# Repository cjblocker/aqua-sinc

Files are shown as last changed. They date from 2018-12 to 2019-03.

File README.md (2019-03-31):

# AquaSinc

A small home-made aquarium controller built around an ARM Cortex M4 STM32f and a Raspberry Pi

## Reference

- 1Bitsy Pinout [ https://github.com/esden/1BitSy ]

## Parts
- 3.3V LDO [ https://www.arrow.com/en/products/mcp1703a-3302edb/microchip-technology ]
- Green Chip LED [ https://www.arrow.com/en/products/kpg-1608vgc-a/kingbright ]

## Dev Instructions for Black Magic Probe

Putting these here because I forget...

1. `$ arm-none-eabi-gdb src/main.elf` or `make debug`
    Upon start up of gdb, these should automatically be exectured from .gdbinit
    ```bash
    (gdb) set target-async on
    (gdb) set confirm off
    (gdb) set mem inaccessible-by-default off
    (gdb) target extended-remote /dev/cu.usbmodem7BAB88A81
    (gdb) monitor version
    (gdb) monitor swdp_scan
    (gdb) attach 1
    ```
2. Load the program from the connected computer with `load`
3. Use any of the following to debug
    * `run` - start or restart the program
    * `start` - run till the beginning of the main function, restart if needed
    * `Ctrl-C` - interrupt the program while running
    * `continue` - resume running after being stopped
    * `next` - run next line of program (but don't step into functions)
    * `step` - like next, but steps into a function
    * `finish` - run till you leave the current function
    * `list [line number]` - show 10 lines surrounding [line number], current line by default
    * `info locals` - print out local variables
    * `set variable <var_name>=<value>` - set variable _var_name_ to _value_
    * `break <line_number>` - set a breakpoint at _line_number_
    * `info breakpoints` - list current breakpoints
    * `disable breakpoints`
    * `delete breakpoints`
    * `watch <var_name>` - set a watchpoint on variable _var_name_
    * `print <expression>` - evaluates expression and prints it
    * `printf <format_string>,<var_name>` - place _var_name_ in the format string at points with %d,%s,etc
    * `commands ... end` - execute the given commands after the previously created watchpoint is changed. 
        Example:
        ```bash
        (gdb) watch blink_count
        (gdb) commands
        > printf "blink extend condition %d\n", blink_count^4
        > end
        ```
4. If you make changes to main.c, you can run make from within gdb, followed by `load`.
5. `quit` to exit gdb or `Ctrl-D`

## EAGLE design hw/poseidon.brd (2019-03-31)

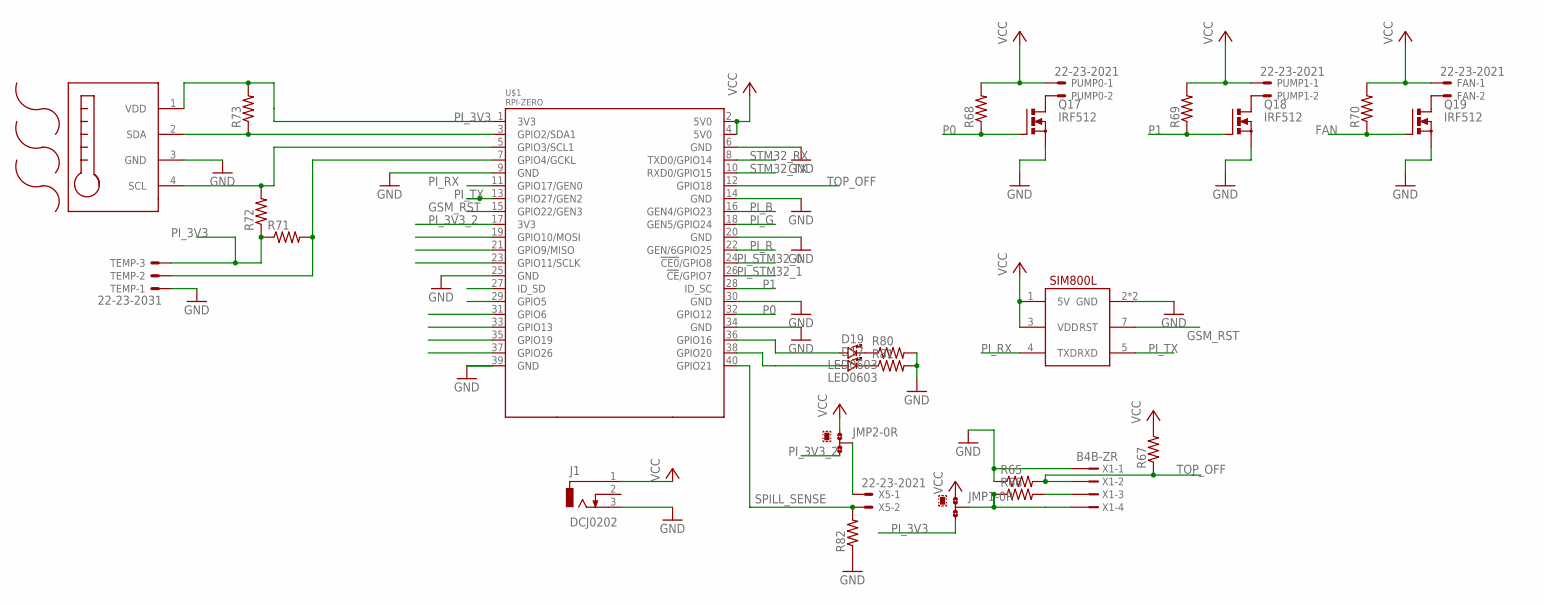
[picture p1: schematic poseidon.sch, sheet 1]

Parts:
D17, D19: LED0603; LED-0603
FAN: 22-23-2021
J1: DCJ0202
JMP1, JMP2: 0R-JUMPA; A0R-JMP
PUMP0, PUMP1: 22-23-2021
Q17, Q18, Q19: IRF512; TO220BV
R65, R66, R68, R69, R70, R71, R72, R73, R80, R81, R82: R-US_R0805; R0805
R67: R-US_M0805; M0805
TEMP: 22-23-2031
U$1: RPI-ZERO; RASPBERRYPI_BASTELSTUBE_V13_RASPI_BOARD_B+_FULL
U$3: AM2320; 4PIN_SMD
U$21: SIM800L; SIP
X1: B4B-ZR
X5: 22-23-2021

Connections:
FAN: Q19.G, R70.1; also elsewhere on the board
GND: J1.3, Q17.S, Q18.S, Q19.S, R65.1, R80.2, R81.2, R82.1, TEMP.1, U$1.6 (GND), U$1.9 (GND), U$1.14 (GND), U$1.20 (GND), U$1.25 (GND), U$1.30 (GND), U$1.34 (GND), U$1.39 (GND), U$3.3 (GND), U$21.2 (GND), U$21.6 (GND), X1.1; also elsewhere on the board
GSM_RST: U$1.15 (GPIO22/GEN3), U$21.7 (RST)
unnamed: PUMP0.2, Q17.D
unnamed: D19.C (CATHODE), R80.1
unnamed: R66.2, X1.3
unnamed: JMP1.2, R66.1, X1.4
unnamed: PUMP1.2, Q18.D
unnamed: D17.C (CATHODE), R81.1
unnamed: FAN.2, Q19.D
unnamed: R71.2, TEMP.2, U$1.7 (GPIO4/GCKL)
unnamed: R73.1, U$1.3 (GPIO2/SDA1), U$3.2 (SDA)
unnamed: R72.2, U$1.5 (GPIO3/SCL1), U$3.4 (SCL)
unnamed: D19.A (ANODE), U$1.36 (GPIO16)
unnamed: D17.A (ANODE), U$1.38 (GPIO20)
unnamed: JMP2.2, X5.1
P0: Q17.G, R68.1, U$1.32 (GPIO12)
P1: Q18.G, R69.1, U$1.28 (ID_SC)
PI_3V3: JMP1.3, R71.1, R72.1, R73.2, TEMP.3, U$1.1 (3V3), U$3.1 (VDD); also elsewhere on the board
PI_3V3_2: JMP2.3, U$1.17 (3V3)
PI_B: U$1.16 (GEN4/GPIO23); also elsewhere on the board
PI_G: U$1.18 (GEN5/GPIO24); also elsewhere on the board
PI_R: U$1.22 (GEN/6GPIO25); also elsewhere on the board
PI_RX: U$1.11 (GPIO17/GEN0), U$21.4 (TXD)
PI_STM32_0: U$1.24 (!CE0!/GPIO8); also elsewhere on the board
PI_STM32_1: U$1.26 (!CE!/GPIO7); also elsewhere on the board
PI_TX: U$1.13 (GPIO27/GEN2), U$21.5 (RXD)
SPILL_SENSE: R82.2, U$1.40 (GPIO21), X5.2
STM32_RX: U$1.8 (TXD0/GPIO14); also elsewhere on the board
STM32_TX: U$1.10 (RXD0/GPIO15); also elsewhere on the board
TOP_OFF: R65.2, R67.1, U$1.12 (GPIO18), X1.2
VCC: FAN.1, J1.1, JMP1.1, JMP2.1, PUMP0.1, PUMP1.1, R67.2, R68.2, R69.2, R70.2, U$1.2 (5V0), U$1.4 (5V0), U$21.1 (5V), U$21.3 (VDD); also elsewhere on the board

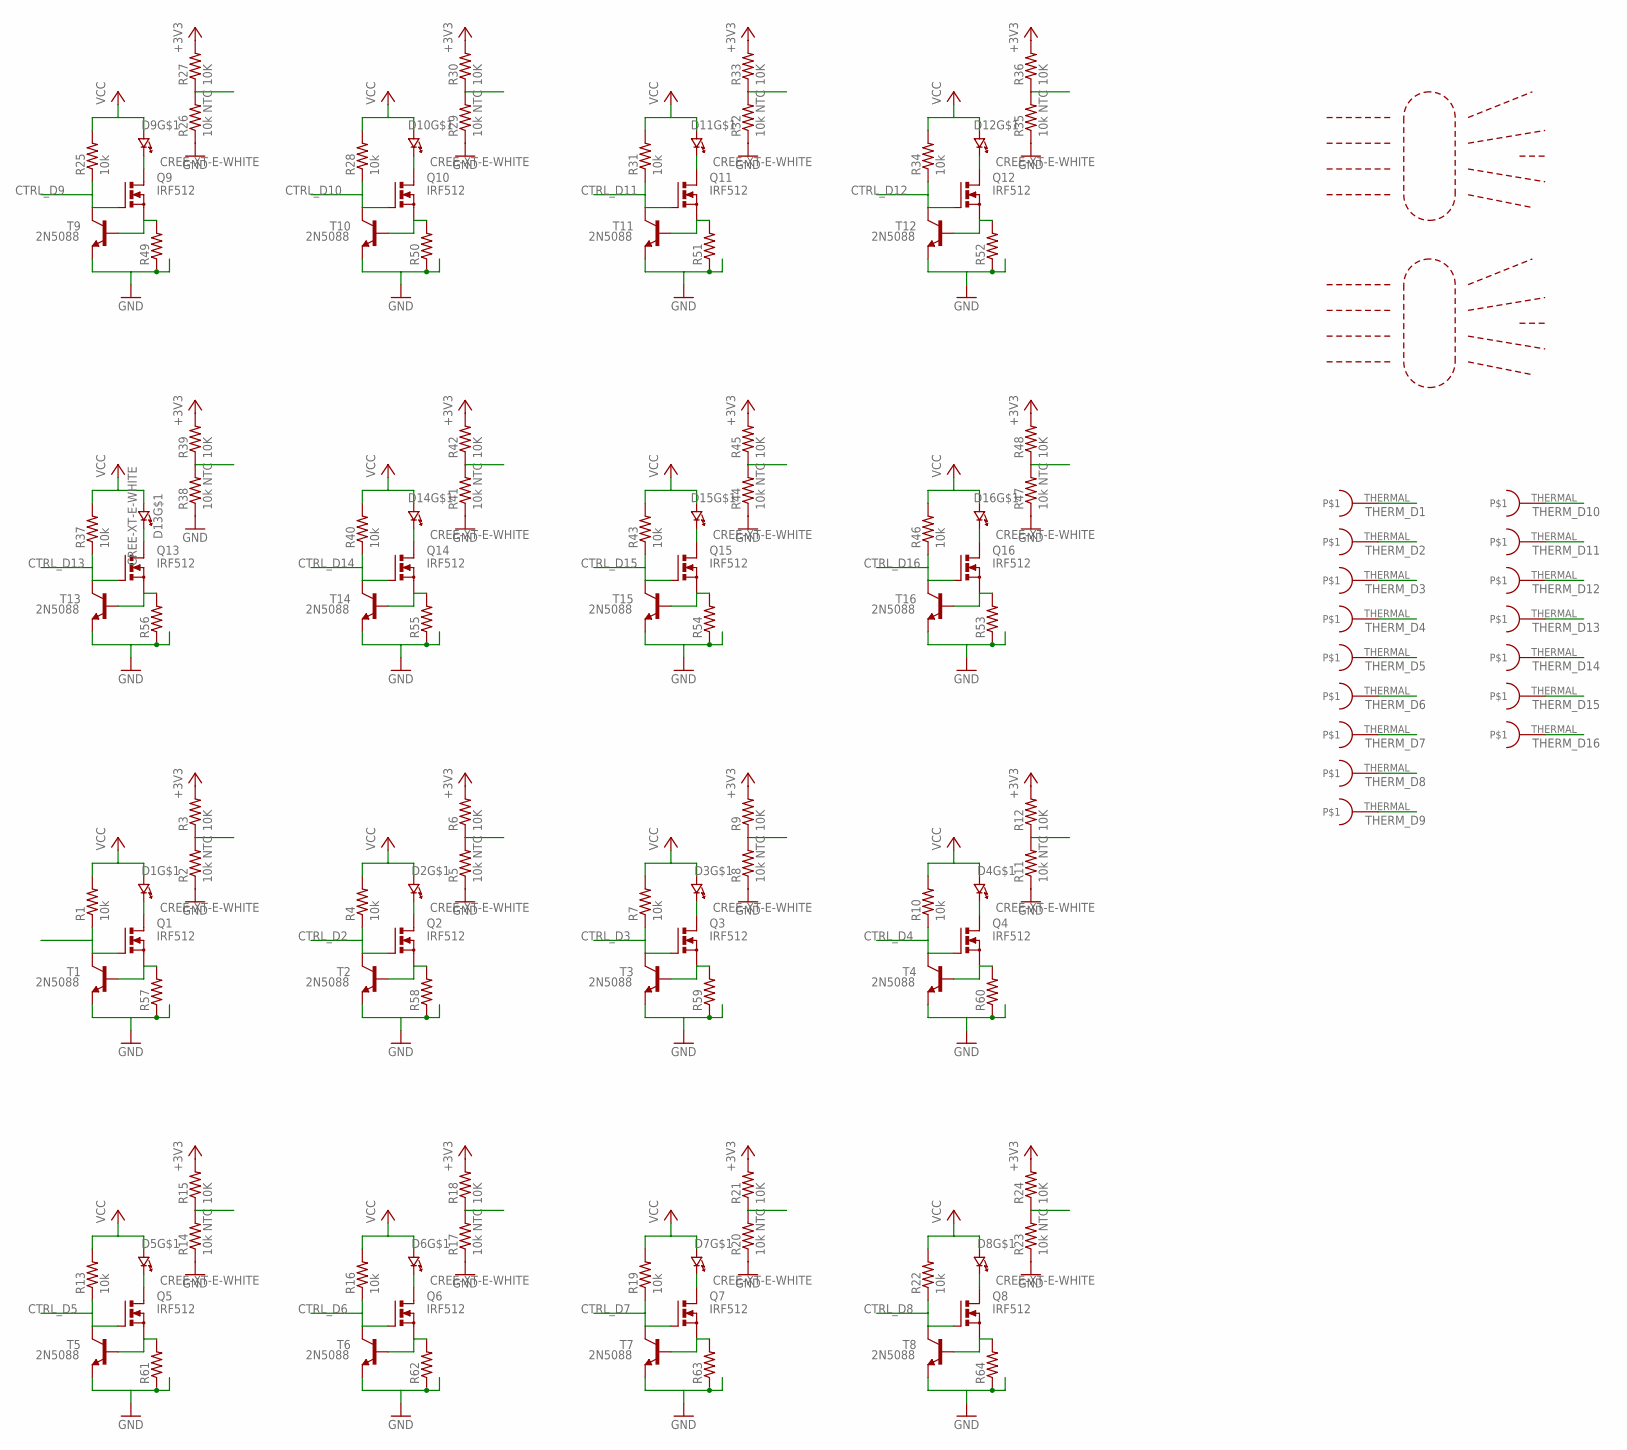
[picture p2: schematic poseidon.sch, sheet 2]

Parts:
D1, D2, D3, D4, D5, D6, D7, D8, D9, D10, D11, D12, D13, D14, D15, D16: CREE-XT-E-WHITE; CREE-XT-E
Q1, Q2, Q3, Q4, Q5, Q6, Q7, Q8, Q9, Q10, Q11, Q12, Q13, Q14, Q15, Q16: IRF512; TO220BV
R1, R4, R7, R10, R13, R16, R19, R22, R25, R28, R31, R34, R37, R40, R43, R46: 10k; R0805
R2, R5, R8, R11, R14, R17, R20, R23, R26, R29, R32, R35, R38, R41, R44, R47: 10k NTC; R0805
R3, R6, R9, R12, R15, R18, R21, R24, R27, R30, R33, R36, R39, R42, R45, R48: 10K; R0603
R49, R50, R51, R52, R53, R54, R55, R56, R57, R58, R59, R60, R61, R62, R63, R64: R-US_R2512; R2512
T1, T2, T3, T4, T5, T6, T7, T8, T9, T10, T11, T12, T13, T14, T15, T16: 2N5088; TO92
U$19, U$20: 8X_LED_OPTIC; FOCUS_GRID

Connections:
+3V3: R3.2, R6.2, R9.2, R12.2, R15.2, R18.2, R21.2, R24.2, R27.2, R30.2, R33.2, R36.2, R39.2, R42.2, R45.2, R48.2; also elsewhere on the board
CTRL_D1: Q1.G, R1.1, T1.1 (C); also elsewhere on the board
CTRL_D2: Q2.G, R4.1, T2.1 (C); also elsewhere on the board
CTRL_D3: Q3.G, R7.1, T3.1 (C); also elsewhere on the board
CTRL_D4: Q4.G, R10.1, T4.1 (C); also elsewhere on the board
CTRL_D5: Q5.G, R13.1, T5.1 (C); also elsewhere on the board
CTRL_D6: Q6.G, R16.1, T6.1 (C); also elsewhere on the board
CTRL_D7: Q7.G, R19.1, T7.1 (C); also elsewhere on the board
CTRL_D8: Q8.G, R22.1, T8.1 (C); also elsewhere on the board
CTRL_D9: Q9.G, R25.1, T9.1 (C); also elsewhere on the board
CTRL_D10: Q10.G, R28.1, T10.1 (C); also elsewhere on the board
CTRL_D11: Q11.G, R31.1, T11.1 (C); also elsewhere on the board
CTRL_D12: Q12.G, R34.1, T12.1 (C); also elsewhere on the board
CTRL_D13: Q13.G, R37.1, T13.1 (C); also elsewhere on the board
CTRL_D14: Q14.G, R40.1, T14.1 (C); also elsewhere on the board
CTRL_D15: Q15.G, R43.1, T15.1 (C); also elsewhere on the board
CTRL_D16: Q16.G, R46.1, T16.1 (C); also elsewhere on the board
GND: R2.1, R5.1, R8.1, R11.1, R14.1, R17.1, R20.1, R23.1, R26.1, R29.1, R32.1, R35.1, R38.1, R41.1, R44.1, R47.1, R49.1, R50.1, R51.1, R52.1, R53.1, R54.1, R55.1, R56.1, R57.1, R58.1, R59.1, R60.1, R61.1, R62.1, R63.1, R64.1, T1.3 (E), T2.3 (E), T3.3 (E), T4.3 (E), T5.3 (E), T6.3 (E), T7.3 (E), T8.3 (E), T9.3 (E), T10.3 (E), T11.3 (E), T12.3 (E), T13.3 (E), T14.3 (E), T15.3 (E), T16.3 (E); also elsewhere on the board
unnamed: D1.K (CATHODE), Q1.D
unnamed: Q1.S, R57.2, T1.2 (B)
unnamed: D2.K (CATHODE), Q2.D
unnamed: Q2.S, R58.2, T2.2 (B)
unnamed: D3.K (CATHODE), Q3.D
unnamed: Q3.S, R59.2, T3.2 (B)
unnamed: D4.K (CATHODE), Q4.D
unnamed: Q4.S, R60.2, T4.2 (B)
unnamed: D5.K (CATHODE), Q5.D
unnamed: Q5.S, R61.2, T5.2 (B)
unnamed: D6.K (CATHODE), Q6.D
unnamed: Q6.S, R62.2, T6.2 (B)
unnamed: D7.K (CATHODE), Q7.D
unnamed: Q7.S, R63.2, T7.2 (B)
unnamed: D8.K (CATHODE), Q8.D
unnamed: Q8.S, R64.2, T8.2 (B)
unnamed: D9.K (CATHODE), Q9.D
unnamed: Q9.S, R49.2, T9.2 (B)
unnamed: D10.K (CATHODE), Q10.D
unnamed: Q10.S, R50.2, T10.2 (B)
unnamed: D11.K (CATHODE), Q11.D
unnamed: Q11.S, R51.2, T11.2 (B)
unnamed: D12.K (CATHODE), Q12.D
unnamed: Q12.S, R52.2, T12.2 (B)
unnamed: D13.K (CATHODE), Q13.D
unnamed: Q13.S, R56.2, T13.2 (B)
unnamed: D14.K (CATHODE), Q14.D
unnamed: Q14.S, R55.2, T14.2 (B)
unnamed: D15.K (CATHODE), Q15.D
unnamed: Q15.S, R54.2, T15.2 (B)
unnamed: D16.K (CATHODE), Q16.D
unnamed: Q16.S, R53.2, T16.2 (B)
TEMP_D1: R41.2, R42.1; also elsewhere on the board
TEMP_D2: R8.2, R9.1; also elsewhere on the board
TEMP_D3: R14.2, R15.1; also elsewhere on the board
TEMP_D4: R17.2, R18.1; also elsewhere on the board
TEMP_D5: R44.2, R45.1; also elsewhere on the board
TEMP_D6: R47.2, R48.1; also elsewhere on the board
TEMP_D7: R11.2, R12.1; also elsewhere on the board
TEMP_D8: R20.2, R21.1; also elsewhere on the board
TEMP_D9: R32.2, R33.1; also elsewhere on the board
TEMP_D10: R29.2, R30.1; also elsewhere on the board
TEMP_D11: R26.2, R27.1; also elsewhere on the board
TEMP_D12: R23.2, R24.1; also elsewhere on the board
TEMP_D13: R5.2, R6.1; also elsewhere on the board
TEMP_D14: R35.2, R36.1; also elsewhere on the board
TEMP_D15: R38.2, R39.1; also elsewhere on the board
TEMP_D16: R2.2, R3.1; also elsewhere on the board
THERM_D1: D1.THERMAL
THERM_D2: D2.THERMAL
THERM_D3: D3.THERMAL
THERM_D4: D4.THERMAL
THERM_D5: D5.THERMAL
THERM_D6: D6.THERMAL
THERM_D7: D7.THERMAL
THERM_D8: D8.THERMAL
THERM_D9: D9.THERMAL
THERM_D10: D10.THERMAL
THERM_D11: D11.THERMAL
THERM_D12: D12.THERMAL
THERM_D13: D13.THERMAL
THERM_D14: D14.THERMAL
THERM_D15: D15.THERMAL
THERM_D16: D16.THERMAL
VCC: D1.A (ANODE), D2.A (ANODE), D3.A (ANODE), D4.A (ANODE), D5.A (ANODE), D6.A (ANODE), D7.A (ANODE), D8.A (ANODE), D9.A (ANODE), D10.A (ANODE), D11.A (ANODE), D12.A (ANODE), D13.A (ANODE), D14.A (ANODE), D15.A (ANODE), D16.A (ANODE), R1.2, R4.2, R7.2, R10.2, R13.2, R16.2, R19.2, R22.2, R25.2, R28.2, R31.2, R34.2, R37.2, R40.2, R43.2, R46.2; also elsewhere on the board

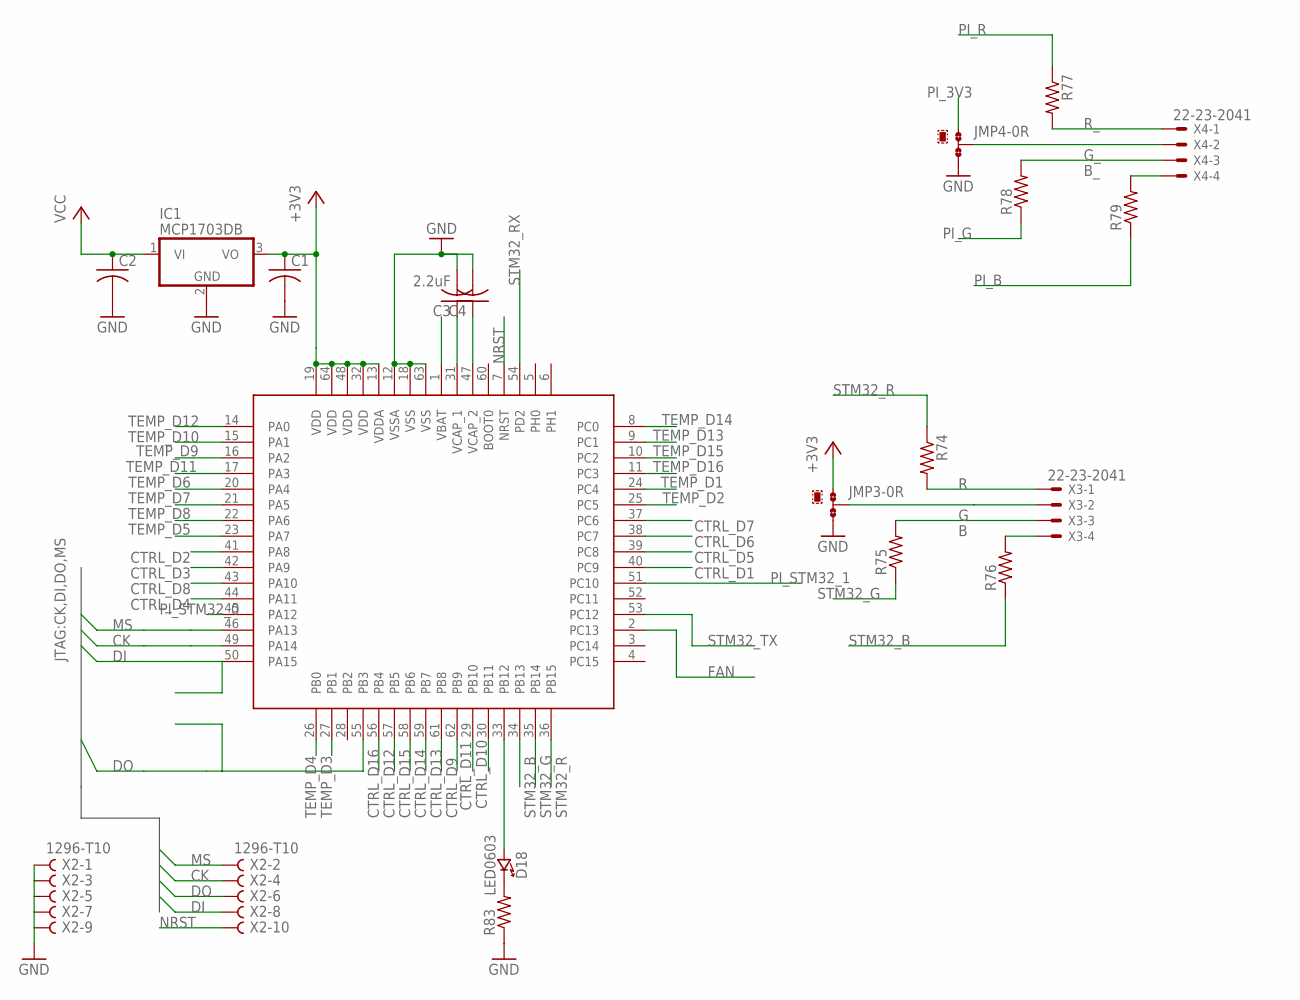
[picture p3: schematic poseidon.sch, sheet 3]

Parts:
C1, C2: C-USC0805; C0805
C3: 2.2uF; C0402K
C4: C-USC0402K; C0402K
D18: LED0603; LED-0603
IC1: MCP1703DB; SOT223
JMP3, JMP4: 0R-JUMPA; A0R-JMP
R74, R75, R76, R77, R78, R79, R83: R-US_R0805; R0805
U$2: STM32F41; QFP50P1200X1200X160-64
X2: 1296-T10; 1296-10
X3, X4: 22-23-2041

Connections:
+3V3: C1.1, IC1.3 (VO), JMP3.1, U$2.13 (VDDA), U$2.19 (VDD), U$2.32 (VDD), U$2.48 (VDD), U$2.64 (VDD); also elsewhere on the board
B: R76.2, X3.4
B_: R79.2, X4.4
CK: U$2.49 (PA14), X2.4
CTRL_D1: U$2.40 (PC9); also elsewhere on the board
CTRL_D2: U$2.41 (PA8); also elsewhere on the board
CTRL_D3: U$2.42 (PA9); also elsewhere on the board
CTRL_D4: U$2.44 (PA11); also elsewhere on the board
CTRL_D5: U$2.39 (PC8); also elsewhere on the board
CTRL_D6: U$2.38 (PC7); also elsewhere on the board
CTRL_D7: U$2.37 (PC6); also elsewhere on the board
CTRL_D8: U$2.43 (PA10); also elsewhere on the board
CTRL_D9: U$2.62 (PB9); also elsewhere on the board
CTRL_D10: U$2.30 (PB11); also elsewhere on the board
CTRL_D11: U$2.29 (PB10); also elsewhere on the board
CTRL_D12: U$2.57 (PB5); also elsewhere on the board
CTRL_D13: U$2.61 (PB8); also elsewhere on the board
CTRL_D14: U$2.59 (PB7); also elsewhere on the board
CTRL_D15: U$2.58 (PB6); also elsewhere on the board
CTRL_D16: U$2.56 (PB4); also elsewhere on the board
DI: U$2.50 (PA15), X2.8
DO: U$2.55 (PB3), X2.6
FAN: U$2.2 (PC13); also elsewhere on the board
G: R75.2, X3.3
GND: C1.2, C2.2, C3.2, C4.2, IC1.2 (GND), JMP3.3, JMP4.3, R83.1, U$2.12 (VSSA), U$2.18 (VSS), U$2.63 (VSS), X2.1, X2.3, X2.5, X2.7, X2.9; also elsewhere on the board
G_: R78.2, X4.3
MS: U$2.46 (PA13), X2.2
unnamed: JMP4.2, X4.2
unnamed: JMP3.2, X3.2
unnamed: D18.C (CATHODE), R83.2
unnamed: D18.A (ANODE), U$2.33 (PB12)
unnamed: C3.1, U$2.31 (VCAP_1)
unnamed: C4.1, U$2.47 (VCAP_2)
NRST: U$2.7 (NRST), X2.10
PI_3V3: JMP4.1; also elsewhere on the board
PI_B: R79.1; also elsewhere on the board
PI_G: R78.1; also elsewhere on the board
PI_R: R77.1; also elsewhere on the board
PI_STM32_0: U$2.45 (PA12); also elsewhere on the board
PI_STM32_1: U$2.51 (PC10); also elsewhere on the board
R: R74.2, X3.1
R_: R77.2, X4.1
STM32_B: R76.1, U$2.34 (PB13)
STM32_G: R75.1, U$2.35 (PB14)
STM32_R: R74.1, U$2.36 (PB15)
STM32_RX: U$2.54 (PD2); also elsewhere on the board
STM32_TX: U$2.53 (PC12); also elsewhere on the board
TEMP_D1: U$2.24 (PC4); also elsewhere on the board
TEMP_D2: U$2.25 (PC5); also elsewhere on the board
TEMP_D3: U$2.27 (PB1); also elsewhere on the board
TEMP_D4: U$2.26 (PB0); also elsewhere on the board
TEMP_D5: U$2.23 (PA7); also elsewhere on the board
TEMP_D6: U$2.20 (PA4); also elsewhere on the board
TEMP_D7: U$2.21 (PA5); also elsewhere on the board
TEMP_D8: U$2.22 (PA6); also elsewhere on the board
TEMP_D9: U$2.16 (PA2); also elsewhere on the board
TEMP_D10: U$2.15 (PA1); also elsewhere on the board
TEMP_D11: U$2.17 (PA3); also elsewhere on the board
TEMP_D12: U$2.14 (PA0); also elsewhere on the board
TEMP_D13: U$2.9 (PC1); also elsewhere on the board
TEMP_D14: U$2.8 (PC0); also elsewhere on the board
TEMP_D15: U$2.10 (PC2); also elsewhere on the board
TEMP_D16: U$2.11 (PC3); also elsewhere on the board
VCC: C2.1, IC1.1 (VI); also elsewhere on the board

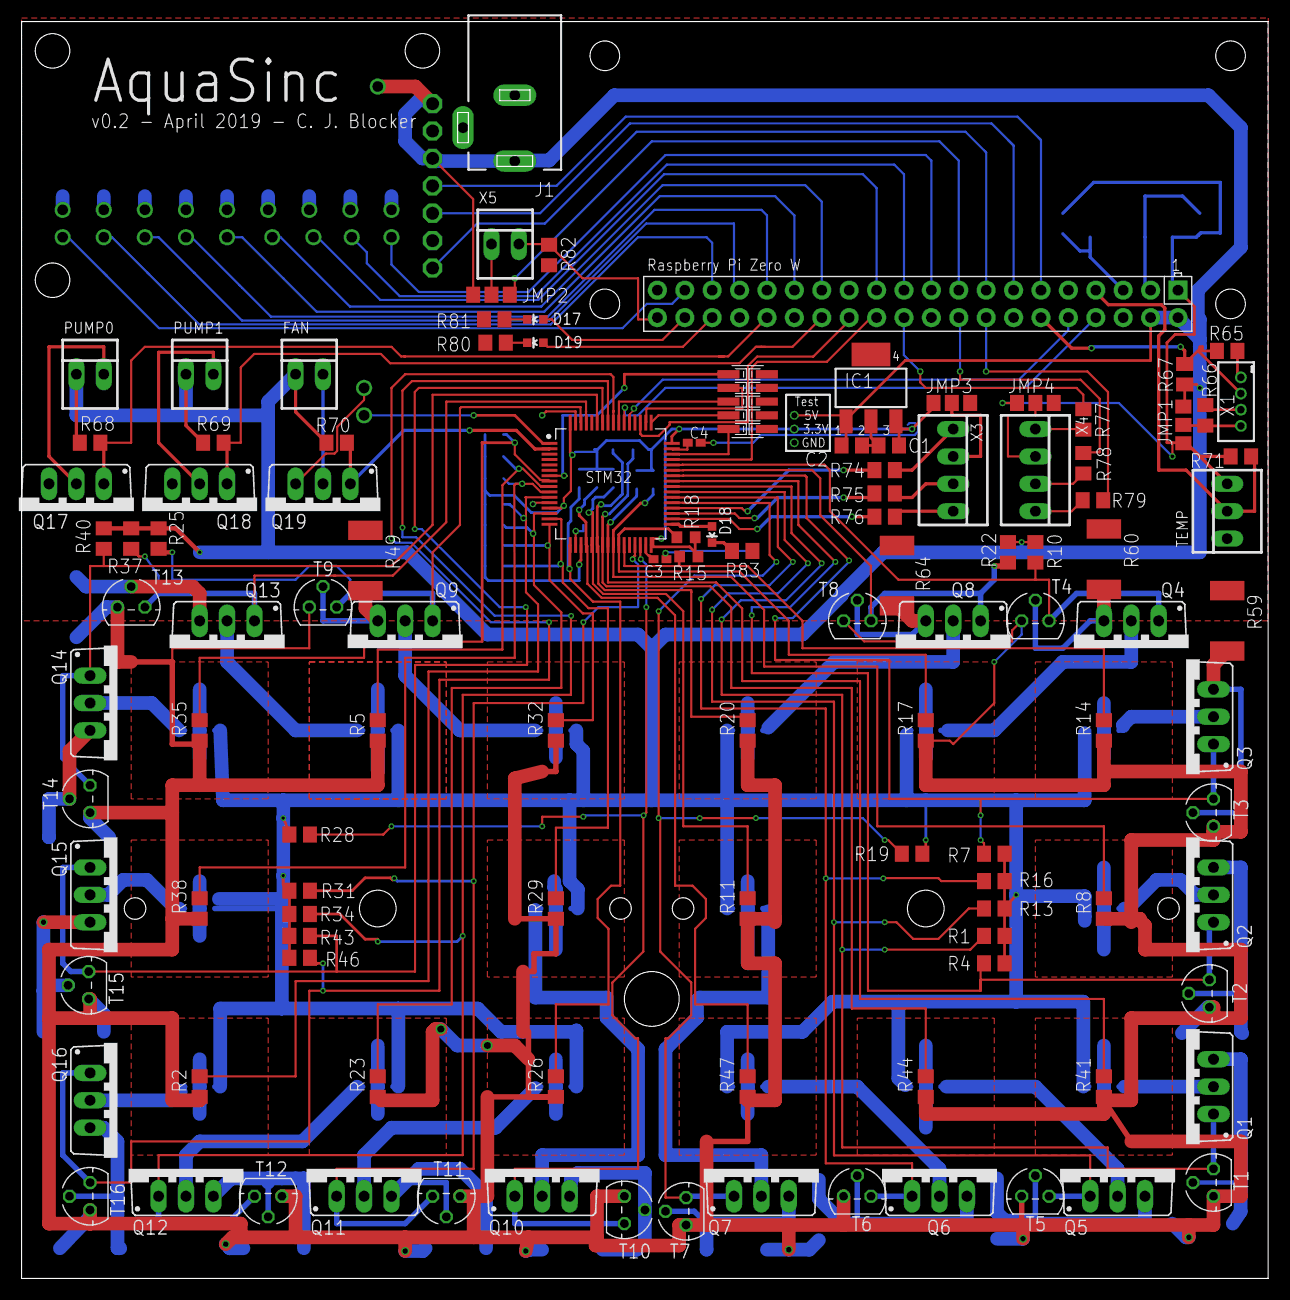
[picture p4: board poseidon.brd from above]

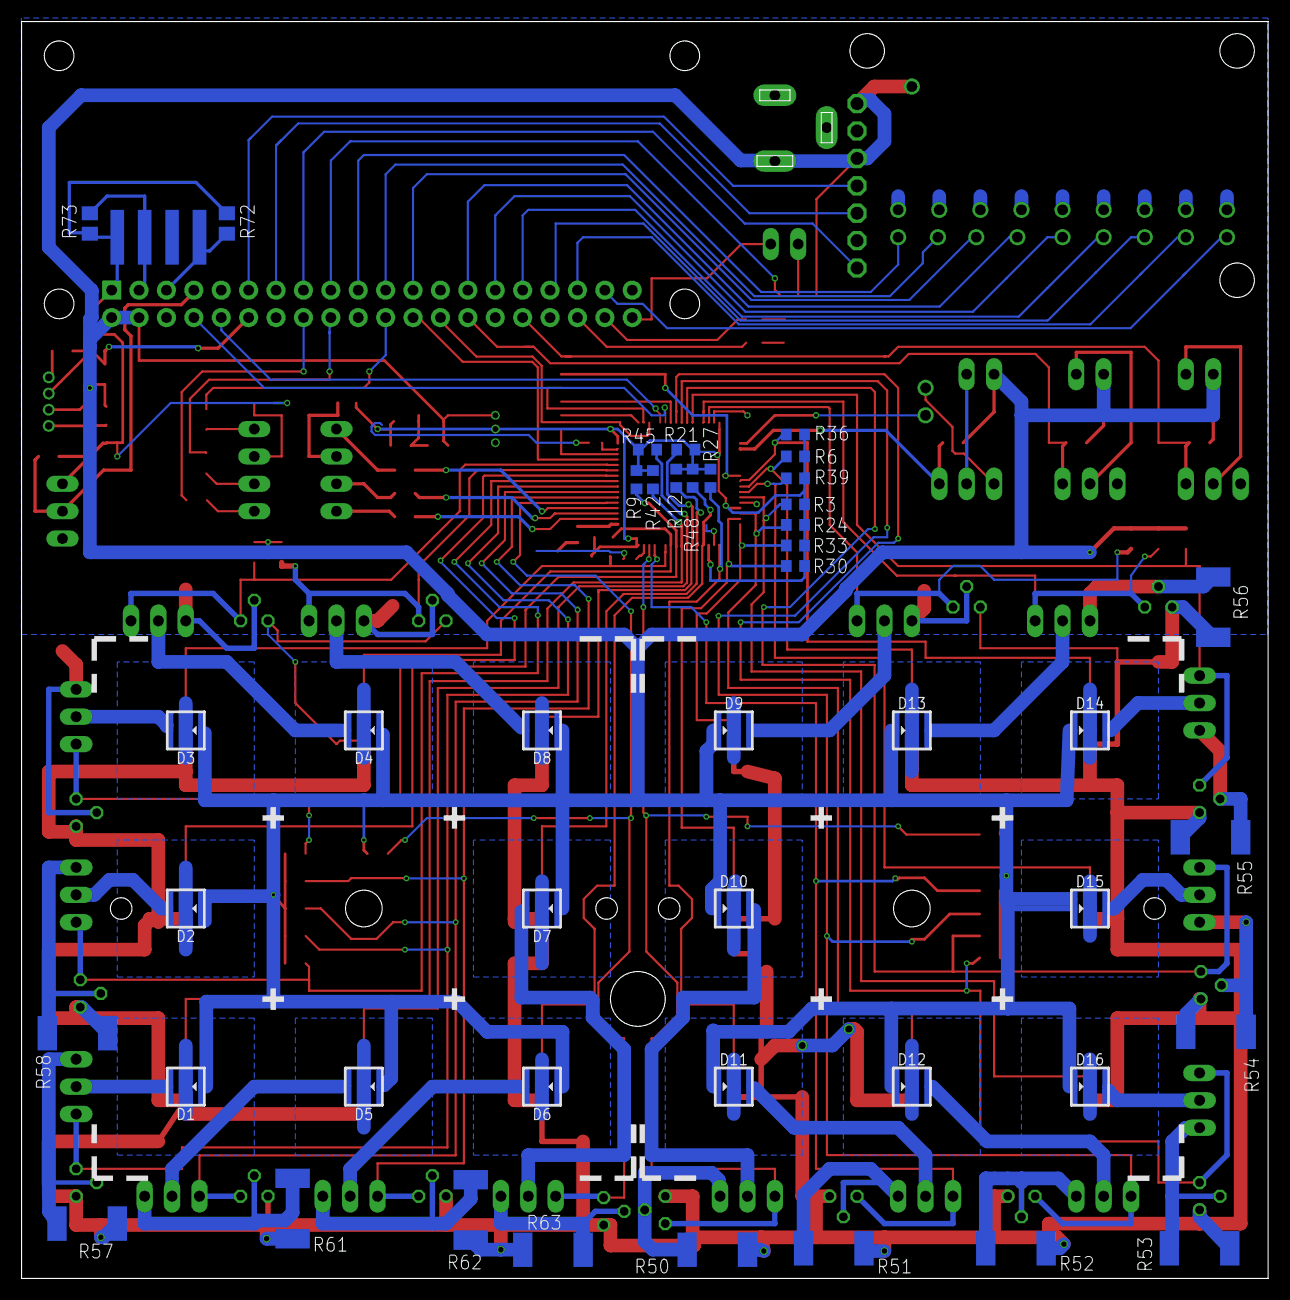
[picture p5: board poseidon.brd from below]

Board: 2 copper layers, 115.5 x 116.5 mm, 162 parts (47 on the bottom side), 117 nets.

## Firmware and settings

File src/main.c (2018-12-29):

#include "../lib/common/button_boot.h"
#include "adc.h"
#include "uart.h"

#include <libopencm3/stm32/rcc.h>
#include <libopencm3/stm32/gpio.h>
#include <libopencm3/stm32/adc.h>
#include <libopencm3/stm32/timer.h>
#include <libopencm3/cm3/scs.h>
#include <stdint.h>
#include <stdio.h>

static const adc_channel temp0 = { // PA0, ADC1 channel 0
    .adc_adc = ADC1,
    .adc_channel = 0,
    .adc_gpio = {
        .gp_port   = GPIOA,
        .gp_pin    = GPIO0,
        .gp_mode   = GPIO_MODE_ANALOG,
        .gp_pupd   = GPIO_PUPD_NONE,
        .gp_af     = 0,
        .gp_ospeed = GPIO_OSPEED_DEFAULT,
        .gp_otype  = GPIO_OTYPE_DEFAULT,
        .gp_level  = 0,
    },
};

static const adc_channel temp1 = { // PA1, ADC1 channel 1
    .adc_adc = ADC1,
    .adc_channel = 1,
    .adc_gpio = {
        .gp_port   = GPIOA,
        .gp_pin    = GPIO1,
        .gp_mode   = GPIO_MODE_ANALOG,
        .gp_pupd   = GPIO_PUPD_NONE,
        .gp_af     = 0,
        .gp_ospeed = GPIO_OSPEED_DEFAULT,
        .gp_otype  = GPIO_OTYPE_DEFAULT,
        .gp_level  = 0,
    },
};

static const adc_channel temp2 = { // PA2, ADC1 channel 2
    .adc_adc = ADC1,
    .adc_channel = 2,
    .adc_gpio = {
        .gp_port   = GPIOA,
        .gp_pin    = GPIO2,
        .gp_mode   = GPIO_MODE_ANALOG,
        .gp_pupd   = GPIO_PUPD_NONE,
        .gp_af     = 0,
        .gp_ospeed = GPIO_OSPEED_DEFAULT,
        .gp_otype  = GPIO_OTYPE_DEFAULT,
        .gp_level  = 0,
    },
};

static const adc_channel temp3 = { // PA3, ADC1 channel 3
    .adc_adc = ADC1,
    .adc_channel = 3,
    .adc_gpio = {
        .gp_port   = GPIOA,
        .gp_pin    = GPIO3,
        .gp_mode   = GPIO_MODE_ANALOG,
        .gp_pupd   = GPIO_PUPD_NONE,
        .gp_af     = 0,
        .gp_ospeed = GPIO_OSPEED_DEFAULT,
        .gp_otype  = GPIO_OTYPE_DEFAULT,
        .gp_level  = 0,
    },
};

static const adc_channel temp4 = { // PA4, ADC1 channel 4
    .adc_adc = ADC1,
    .adc_channel = 4,
    .adc_gpio = {
        .gp_port   = GPIOA,
        .gp_pin    = GPIO4,
        .gp_mode   = GPIO_MODE_ANALOG,
        .gp_pupd   = GPIO_PUPD_NONE,
        .gp_af     = 0,
        .gp_ospeed = GPIO_OSPEED_DEFAULT,
        .gp_otype  = GPIO_OTYPE_DEFAULT,
        .gp_level  = 0,
    },
};

static const adc_channel temp5 = { // PA5, ADC1 channel 5
    .adc_adc = ADC1,
    .adc_channel = 5,
    .adc_gpio = {
        .gp_port   = GPIOA,
        .gp_pin    = GPIO5,
        .gp_mode   = GPIO_MODE_ANALOG,
        .gp_pupd   = GPIO_PUPD_NONE,
        .gp_af     = 0,
        .gp_ospeed = GPIO_OSPEED_DEFAULT,
        .gp_otype  = GPIO_OTYPE_DEFAULT,
        .gp_level  = 0,
    },
};

static const adc_channel temp6 = { // PA6, ADC1 channel 6
    .adc_adc = ADC1,
    .adc_channel = 6,
    .adc_gpio = {
        .gp_port   = GPIOA,
        .gp_pin    = GPIO6,
        .gp_mode   = GPIO_MODE_ANALOG,
        .gp_pupd   = GPIO_PUPD_NONE,
        .gp_af     = 0,
        .gp_ospeed = GPIO_OSPEED_DEFAULT,
        .gp_otype  = GPIO_OTYPE_DEFAULT,
        .gp_level  = 0,
    },
};

static const adc_channel temp7 = { // PA7, ADC1 channel 7
    .adc_adc = ADC1,
    .adc_channel = 7,
    .adc_gpio = {
        .gp_port   = GPIOA,
        .gp_pin    = GPIO7,
        .gp_mode   = GPIO_MODE_ANALOG,
        .gp_pupd   = GPIO_PUPD_NONE,
        .gp_af     = 0,
        .gp_ospeed = GPIO_OSPEED_DEFAULT,
        .gp_otype  = GPIO_OTYPE_DEFAULT,
        .gp_level  = 0,
    },
};

static const adc_channel temp8 = { // PB0, ADC1 channel 8
    .adc_adc = ADC1,
    .adc_channel = 8,
    .adc_gpio = {
        .gp_port   = GPIOB,
        .gp_pin    = GPIO0,
        .gp_mode   = GPIO_MODE_ANALOG,
        .gp_pupd   = GPIO_PUPD_NONE,
        .gp_af     = 0,
        .gp_ospeed = GPIO_OSPEED_DEFAULT,
        .gp_otype  = GPIO_OTYPE_DEFAULT,
        .gp_level  = 0,
    },
};

static const adc_channel temp9 = { // PB1, ADC1 channel 9
    .adc_adc = ADC1,
    .adc_channel = 9,
    .adc_gpio = {
        .gp_port   = GPIOB,
        .gp_pin    = GPIO1,
        .gp_mode   = GPIO_MODE_ANALOG,
        .gp_pupd   = GPIO_PUPD_NONE,
        .gp_af     = 0,
        .gp_ospeed = GPIO_OSPEED_DEFAULT,
        .gp_otype  = GPIO_OTYPE_DEFAULT,
        .gp_level  = 0,
    },
};

static const adc_channel temp10 = { // PC0, ADC1 channel 10
    .adc_adc = ADC1,
    .adc_channel = 10,
    .adc_gpio = {
        .gp_port   = GPIOC,
        .gp_pin    = GPIO0,
        .gp_mode   = GPIO_MODE_ANALOG,
        .gp_pupd   = GPIO_PUPD_NONE,
        .gp_af     = 0,
        .gp_ospeed = GPIO_OSPEED_DEFAULT,
        .gp_otype  = GPIO_OTYPE_DEFAULT,
        .gp_level  = 0,
    },
};

static const adc_channel temp11 = { // PC1, ADC1 channel 11
    .adc_adc = ADC1,
    .adc_channel = 11,
    .adc_gpio = {
        .gp_port   = GPIOC,
        .gp_pin    = GPIO1,
        .gp_mode   = GPIO_MODE_ANALOG,
        .gp_pupd   = GPIO_PUPD_NONE,
        .gp_af     = 0,
        .gp_ospeed = GPIO_OSPEED_DEFAULT,
        .gp_otype  = GPIO_OTYPE_DEFAULT,
        .gp_level  = 0,
    },
};

static const adc_channel temp12 = { // PC2, ADC1 channel 12
    .adc_adc = ADC1,
    .adc_channel = 12,
    .adc_gpio = {
        .gp_port   = GPIOC,
        .gp_pin    = GPIO2,
        .gp_mode   = GPIO_MODE_ANALOG,
        .gp_pupd   = GPIO_PUPD_NONE,
        .gp_af     = 0,
        .gp_ospeed = GPIO_OSPEED_DEFAULT,
        .gp_otype  = GPIO_OTYPE_DEFAULT,
        .gp_level  = 0,
    },
};

static const adc_channel temp13 = { // PC3, ADC1 channel 13
    .adc_adc = ADC1,
    .adc_channel = 13,
    .adc_gpio = {
        .gp_port   = GPIOC,
        .gp_pin    = GPIO3,
        .gp_mode   = GPIO_MODE_ANALOG,
        .gp_pupd   = GPIO_PUPD_NONE,
        .gp_af     = 0,
        .gp_ospeed = GPIO_OSPEED_DEFAULT,
        .gp_otype  = GPIO_OTYPE_DEFAULT,
        .gp_level  = 0,
    },
};

static const adc_channel temp14 = { // PC4, ADC1 channel 14
    .adc_adc = ADC1,
    .adc_channel = 14,
    .adc_gpio = {
        .gp_port   = GPIOC,
        .gp_pin    = GPIO4,
        .gp_mode   = GPIO_MODE_ANALOG,
        .gp_pupd   = GPIO_PUPD_NONE,
        .gp_af     = 0,
        .gp_ospeed = GPIO_OSPEED_DEFAULT,
        .gp_otype  = GPIO_OTYPE_DEFAULT,
        .gp_level  = 0,
    },
};

static const adc_channel temp15 = { // PC5, ADC1 channel 15
    .adc_adc = ADC1,
    .adc_channel = 15,
    .adc_gpio = {
        .gp_port   = GPIOC,
        .gp_pin    = GPIO5,
        .gp_mode   = GPIO_MODE_ANALOG,
        .gp_pupd   = GPIO_PUPD_NONE,
        .gp_af     = 0,
        .gp_ospeed = GPIO_OSPEED_DEFAULT,
        .gp_otype  = GPIO_OTYPE_DEFAULT,
        .gp_level  = 0,
    },
};

/*
 * Gamma correction table
 *
 * The nonlinear tables are calculating with the function:
 * Iout = Iin ** gamma
 */
static const uint16_t gamma_table[] = {
	0,		0,		2,		4,		7,		11,		17,		24,
	32,		42,		53,		65,		79,		94,		111,	129,
	148,	169,	192,	216,	242,	270,	299,	330,
	362,	396,	432,	469,	508,	549,	591,	635,
	681,	729,	779,	830,	883,	938,	995,	1053,
	1113,	1175,	1239,	1305,	1373,	1443,	1514,	1587,
	1663,	1740,	1819,	1900,	1983,	2068,	2155,	2243,
	2334,	2427,	2521,	2618,	2717,	2817,	2920,	3024,
	3131,	3240,	3350,	3463,	3578,	3694,	3813,	3934,
	4057,	4182,	4309,	4438,	4570,	4703,	4838,	4976,
	5115,	5257,	5401,	5547,	5695,	5845,	5998,	6152,
	6309,	6468,	6629,	6792,	6957,	7124,	7294,	7466,
	7640,	7816,	7994,	8175,	8358,	8543,	8730,	8919,
	9111,	9305,	9501,	9699,	9900,	10102,	10307,	10515,
	10724,	10936,	11150,	11366,	11585,	11806,	12029,	12254,
	12482,	12712,	12944,	13179,	13416,	13655,	13896,	14140,
	14386,	14635,	14885,	15138,	15394,	15652,	15912,	16174,
	16439,	16706,	16975,	17247,	17521,	17798,	18077,	18358,
	18642,	18928,	19216,	19507,	19800,	20095,	20393,	20694,
	20996,	21301,	21609,	21919,	22231,	22546,	22863,	23182,
	23504,	23829,	24156,	24485,	24817,	25151,	25487,	25826,
	26168,	26512,	26858,	27207,	27558,	27912,	28268,	28627,
	28988,	29351,	29717,	30086,	30457,	30830,	31206,	31585,
	31966,	32349,	32735,	33124,	33514,	33908,	34304,	34702,
	35103,	35507,	35913,	36321,	36732,	37146,	37562,	37981,
	38402,	38825,	39252,	39680,	40112,	40546,	40982,	41421,
	41862,	42306,	42753,	43202,	43654,	44108,	44565,	45025,
	45487,	45951,	46418,	46888,	47360,	47835,	48313,	48793,
	49275,	49761,	50249,	50739,	51232,	51728,	52226,	52727,
	53230,	53736,	54245,	54756,	55270,	55787,	56306,	56828,
	57352,	57879,	58409,	58941,	59476,	60014,	60554,	61097,
	61642,	62190,	62741,	63295,	63851,	64410,	64971,	65535,
};

static void clock_setup(void)
{
	rcc_clock_setup_hse_3v3(&rcc_hse_25mhz_3v3[RCC_CLOCK_3V3_168MHZ]);

	/* Enable clock. */
	rcc_periph_clock_enable(RCC_TIM1);
	rcc_periph_clock_enable(RCC_TIM2);
	rcc_periph_clock_enable(RCC_TIM3);
	rcc_periph_clock_enable(RCC_TIM4);
	rcc_periph_clock_enable(RCC_TIM8);

	/* Enable Alternate Function clocks. */
	rcc_periph_clock_enable(RCC_GPIOA);
	rcc_periph_clock_enable(RCC_GPIOB);
	rcc_periph_clock_enable(RCC_GPIOC);
}

static void gpio_setup(void)
{
	/*
	 * Set GPIO8 (in GPIO port A) to
	 * 'output alternate function push-pull'.
	 */

	// PORT A

	// A8 - AF1 - T1 C1
	gpio_mode_setup(GPIOA, GPIO_MODE_AF, GPIO_PUPD_NONE, GPIO8);
  	gpio_set_af(GPIOA, GPIO_AF1, GPIO8);

	// A9 - AF1 - T1 C2
	gpio_mode_setup(GPIOA, GPIO_MODE_AF, GPIO_PUPD_NONE, GPIO9);
  	gpio_set_af(GPIOA, GPIO_AF1, GPIO9);

	// A10 - AF1 - T1 C3
	gpio_mode_setup(GPIOA, GPIO_MODE_AF, GPIO_PUPD_NONE, GPIO10);
  	gpio_set_af(GPIOA, GPIO_AF1, GPIO10);

	// A11 - AF1 - T1 C4
	gpio_mode_setup(GPIOA, GPIO_MODE_AF, GPIO_PUPD_NONE, GPIO11);
  	gpio_set_af(GPIOA, GPIO_AF1, GPIO11);

  	// PORT B

  	// B4 - AF2 - T3 C1
	gpio_mode_setup(GPIOB, GPIO_MODE_AF, GPIO_PUPD_NONE, GPIO4);
  	gpio_set_af(GPIOB, GPIO_AF2, GPIO4);

  	// B5 - AF2 - T3 C2
	gpio_mode_setup(GPIOB, GPIO_MODE_AF, GPIO_PUPD_NONE, GPIO5);
  	gpio_set_af(GPIOB, GPIO_AF2, GPIO5);

  	// B6 - AF2 - T4 C1
	gpio_mode_setup(GPIOB, GPIO_MODE_AF, GPIO_PUPD_NONE, GPIO6);
  	gpio_set_af(GPIOB, GPIO_AF2, GPIO6);

  	// B7 - AF2 - T4 C2
	gpio_mode_setup(GPIOB, GPIO_MODE_AF, GPIO_PUPD_NONE, GPIO7);
  	gpio_set_af(GPIOB, GPIO_AF2, GPIO7);

  	// B8 - AF2 - T4 C3
	gpio_mode_setup(GPIOB, GPIO_MODE_AF, GPIO_PUPD_NONE, GPIO8);
  	gpio_set_af(GPIOB, GPIO_AF2, GPIO8);

  	// B9 - AF2 - T4 C4
	gpio_mode_setup(GPIOB, GPIO_MODE_AF, GPIO_PUPD_NONE, GPIO9);
  	gpio_set_af(GPIOB, GPIO_AF2, GPIO9);

  	// B10 - AF1 - T2 C3
	gpio_mode_setup(GPIOB, GPIO_MODE_AF, GPIO_PUPD_NONE, GPIO10);
  	gpio_set_af(GPIOB, GPIO_AF1, GPIO10);

  	// B11 - AF1 - T2 C4
	gpio_mode_setup(GPIOB, GPIO_MODE_AF, GPIO_PUPD_NONE, GPIO11);
  	gpio_set_af(GPIOB, GPIO_AF1, GPIO11);

  	// PORT C

  	// C6 - AF3 - T8 C1
	gpio_mode_setup(GPIOC, GPIO_MODE_AF, GPIO_PUPD_NONE, GPIO6);
  	gpio_set_af(GPIOC, GPIO_AF3, GPIO6);

  	// C7 - AF3 - T8 C2
	gpio_mode_setup(GPIOC, GPIO_MODE_AF, GPIO_PUPD_NONE, GPIO7);
  	gpio_set_af(GPIOC, GPIO_AF3, GPIO7);

  	// C8 - AF3 - T8 C3
	gpio_mode_setup(GPIOC, GPIO_MODE_AF, GPIO_PUPD_NONE, GPIO8);
  	gpio_set_af(GPIOC, GPIO_AF3, GPIO8);

  	// C9 - AF3 - T8 C4
	gpio_mode_setup(GPIOC, GPIO_MODE_AF, GPIO_PUPD_NONE, GPIO9);
  	gpio_set_af(GPIOC, GPIO_AF3, GPIO9);
}

static void tim_setup_01(void)
{
	/* Reset TIM1 peripheral. */
	timer_reset(TIM1);
	/* Timer global mode:
	* - No divider
	* - Alignment edge
	* - Direction up
	*/
	timer_set_mode(TIM1, TIM_CR1_CKD_CK_INT, TIM_CR1_CMS_EDGE, TIM_CR1_DIR_UP);
	timer_set_prescaler(TIM1, 0);
	timer_set_repetition_counter(TIM1, 0);
	/* Enable preload. */
	timer_disable_preload(TIM1);
	/* Continous mode. */
	timer_continuous_mode(TIM1);
	/* Period (36kHz). */
	timer_set_period(TIM1, 0xFFFF);
	/* Disable outputs. */
	timer_disable_oc_output(TIM1, TIM_OC1);
	timer_disable_oc_output(TIM1, TIM_OC2);
	timer_disable_oc_output(TIM1, TIM_OC3);
	timer_disable_oc_output(TIM1, TIM_OC4);

	timer_set_deadtime(TIM1, 0);
	timer_set_enabled_off_state_in_idle_mode(TIM1);
	timer_set_enabled_off_state_in_run_mode(TIM1);
	timer_disable_break(TIM1);
	timer_set_break_polarity_high(TIM1);
	timer_disable_break_automatic_output(TIM1);
	timer_set_break_lock(TIM1, TIM_BDTR_LOCK_OFF);

	/* -- OC1 configuration -- */
	/* Configure global mode of line 1. */
	timer_disable_oc_clear(TIM1, TIM_OC1);
	timer_enable_oc_preload(TIM1, TIM_OC1);
	timer_set_oc_slow_mode(TIM1, TIM_OC1);
	timer_set_oc_mode(TIM1, TIM_OC1, TIM_OCM_PWM1);
	timer_set_oc_polarity_high(TIM1, TIM_OC1);
	timer_set_oc_idle_state_set(TIM1, TIM_OC1);
	/* Set the capture compare value for OC1 to max value -1 for max duty cycle/brightness. */
	timer_set_oc_value(TIM1, TIM_OC1, 0xFFFF);
	timer_enable_oc_output(TIM1, TIM_OC1);


	/* -- OC2 configuration -- */
	/* Configure global mode of line 2. */
	timer_disable_oc_clear(TIM1, TIM_OC2);
	timer_enable_oc_preload(TIM1, TIM_OC2);
	timer_set_oc_slow_mode(TIM1, TIM_OC2);
	timer_set_oc_mode(TIM1, TIM_OC2, TIM_OCM_PWM1);
	timer_set_oc_polarity_high(TIM1, TIM_OC2);
	timer_set_oc_idle_state_set(TIM1, TIM_OC2);
	/* Set the capture compare value for OC2 to max value -1 for max duty cycle/brightness. */
	timer_set_oc_value(TIM1, TIM_OC2, 0xFFFF);
	timer_enable_oc_output(TIM1, TIM_OC2);


	/* -- OC3 configuration -- */
	/* Configure global mode of line 3. */
	timer_disable_oc_clear(TIM1, TIM_OC3);
	timer_enable_oc_preload(TIM1, TIM_OC3);
	timer_set_oc_slow_mode(TIM1, TIM_OC3);
	timer_set_oc_mode(TIM1, TIM_OC3, TIM_OCM_PWM1);
	timer_set_oc_polarity_high(TIM1, TIM_OC3);
	timer_set_oc_idle_state_set(TIM1, TIM_OC3);
	/* Set the capture compare value for OC3 to max value -1 for max duty cycle/brightness. */
	timer_set_oc_value(TIM1, TIM_OC3, 0xFFFF);
	timer_enable_oc_output(TIM1, TIM_OC3);


	/* -- OC4 configuration -- */
	/* Configure global mode of line 4. */
	timer_disable_oc_clear(TIM1, TIM_OC4);
	timer_enable_oc_preload(TIM1, TIM_OC4);
	timer_set_oc_slow_mode(TIM1, TIM_OC4);
	timer_set_oc_mode(TIM1, TIM_OC4, TIM_OCM_PWM1);
	timer_set_oc_polarity_high(TIM1, TIM_OC4);
	timer_set_oc_idle_state_set(TIM1, TIM_OC4);
	/* Set the capture compare value for OC4 to max value -1 for max duty cycle/brightness. */
	timer_set_oc_value(TIM1, TIM_OC4, 0xFFFF);
	timer_enable_oc_output(TIM1, TIM_OC4);





	timer_enable_preload(TIM1);
	timer_enable_break_main_output(TIM1);
	/* Counter enable. */
	timer_enable_counter(TIM1);

}


static void tim_setup_02(void)
{
	/* Reset TIM2 peripheral. */
	timer_reset(TIM2);
	/* Timer global mode:
	* - No divider
	* - Alignment edge
	* - Direction up
	*/
	timer_set_mode(TIM2, TIM_CR1_CKD_CK_INT, TIM_CR1_CMS_EDGE, TIM_CR1_DIR_UP);
	timer_set_prescaler(TIM2, 0);
	timer_set_repetition_counter(TIM2, 0);
	/* Enable preload. */
	timer_disable_preload(TIM2);
	/* Continous mode. */
	timer_continuous_mode(TIM2);
	/* Period (36kHz). */
	timer_set_period(TIM2, 0xFFFF);
	/* Disable outputs. */
	timer_disable_oc_output(TIM2, TIM_OC1);
	timer_disable_oc_output(TIM2, TIM_OC2);
	timer_disable_oc_output(TIM2, TIM_OC3);
	timer_disable_oc_output(TIM2, TIM_OC4);

	timer_set_deadtime(TIM2, 0);
	timer_set_enabled_off_state_in_idle_mode(TIM2);
	timer_set_enabled_off_state_in_run_mode(TIM2);
	timer_disable_break(TIM2);
	timer_set_break_polarity_high(TIM2);
	timer_disable_break_automatic_output(TIM2);
	timer_set_break_lock(TIM2, TIM_BDTR_LOCK_OFF);


	/* -- OC3 configuration -- */
	/* Configure global mode of line 3. */
	timer_disable_oc_clear(TIM2, TIM_OC3);
	timer_enable_oc_preload(TIM2, TIM_OC3);
	timer_set_oc_slow_mode(TIM2, TIM_OC3);
	timer_set_oc_mode(TIM2, TIM_OC3, TIM_OCM_PWM1);
	timer_set_oc_polarity_high(TIM2, TIM_OC3);
	timer_set_oc_idle_state_set(TIM2, TIM_OC3);
	/* Set the capture compare value for OC3 to max value -1 for max duty cycle/brightness. */
	timer_set_oc_value(TIM2, TIM_OC3, 0xFFFF);
	timer_enable_oc_output(TIM2, TIM_OC3);


	/* -- OC4 configuration -- */
	/* Configure global mode of line 4. */
	timer_disable_oc_clear(TIM2, TIM_OC4);
	timer_enable_oc_preload(TIM2, TIM_OC4);
	timer_set_oc_slow_mode(TIM2, TIM_OC4);
	timer_set_oc_mode(TIM2, TIM_OC4, TIM_OCM_PWM1);
	timer_set_oc_polarity_high(TIM2, TIM_OC4);
	timer_set_oc_idle_state_set(TIM2, TIM_OC4);
	/* Set the capture compare value for OC4 to max value -1 for max duty cycle/brightness. */
	timer_set_oc_value(TIM2, TIM_OC4, 0xFFFF);
	timer_enable_oc_output(TIM2, TIM_OC4);



	timer_enable_preload(TIM2);
	timer_enable_break_main_output(TIM2);
	/* Counter enable. */
	timer_enable_counter(TIM2);

}


static void tim_setup_03(void)
{
	/* Reset TIM3 peripheral. */
	timer_reset(TIM3);
	/* Timer global mode:
	* - No divider
	* - Alignment edge
	* - Direction up
	*/
	timer_set_mode(TIM3, TIM_CR1_CKD_CK_INT, TIM_CR1_CMS_EDGE, TIM_CR1_DIR_UP);
	timer_set_prescaler(TIM3, 0);
	timer_set_repetition_counter(TIM3, 0);
	/* Enable preload. */
	timer_disable_preload(TIM3);
	/* Continous mode. */
	timer_continuous_mode(TIM3);
	/* Period (36kHz). */
	timer_set_period(TIM3, 0xFFFF);
	/* Disable outputs. */
	timer_disable_oc_output(TIM3, TIM_OC1);
	timer_disable_oc_output(TIM3, TIM_OC2);
	timer_disable_oc_output(TIM3, TIM_OC3);
	timer_disable_oc_output(TIM3, TIM_OC4);

	timer_set_deadtime(TIM3, 0);
	timer_set_enabled_off_state_in_idle_mode(TIM3);
	timer_set_enabled_off_state_in_run_mode(TIM3);
	timer_disable_break(TIM3);
	timer_set_break_polarity_high(TIM3);
	timer_disable_break_automatic_output(TIM3);
	timer_set_break_lock(TIM3, TIM_BDTR_LOCK_OFF);

	/* -- OC1 configuration -- */
	/* Configure global mode of line 1. */
	timer_disable_oc_clear(TIM3, TIM_OC1);
	timer_enable_oc_preload(TIM3, TIM_OC1);
	timer_set_oc_slow_mode(TIM3, TIM_OC1);
	timer_set_oc_mode(TIM3, TIM_OC1, TIM_OCM_PWM1);
	timer_set_oc_polarity_high(TIM3, TIM_OC1);
	timer_set_oc_idle_state_set(TIM3, TIM_OC1);
	/* Set the capture compare value for OC1 to max value -1 for max duty cycle/brightness. */
	timer_set_oc_value(TIM3, TIM_OC1, 0xFFFF);
	timer_enable_oc_output(TIM3, TIM_OC1);


	/* -- OC2 configuration -- */
	/* Configure global mode of line 2. */
	timer_disable_oc_clear(TIM3, TIM_OC2);
	timer_enable_oc_preload(TIM3, TIM_OC2);
	timer_set_oc_slow_mode(TIM3, TIM_OC2);
	timer_set_oc_mode(TIM3, TIM_OC2, TIM_OCM_PWM1);
	timer_set_oc_polarity_high(TIM3, TIM_OC2);
	timer_set_oc_idle_state_set(TIM3, TIM_OC2);
	/* Set the capture compare value for OC2 to max value -1 for max duty cycle/brightness. */
	timer_set_oc_value(TIM3, TIM_OC2, 0xFFFF);
	timer_enable_oc_output(TIM3, TIM_OC2);



	timer_enable_preload(TIM3);
	timer_enable_break_main_output(TIM3);
	/* Counter enable. */
	timer_enable_counter(TIM3);

}
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
int main(void)
{
	int i, j0, d0, k;
	volatile uint16_t t0, t1, t2, t3, t4, t5, t6, t7, t8, t9, t10, t11, t12, t13, t14, t15;

	button_boot();

	clock_setup();
	gpio_setup();
	tim_setup();
	adc_setup();
	uart_init();

	/* Enable and initialise the debug monitor handler. */
    SCS_DEMCR |= SCS_DEMCR_VC_MON_EN;
	initialise_monitor_handles();

	j0 = 0;
	d0 = 1;
	k = 0;
	while (1) {
		/* Set the timer compare value to the on time based on the gamma table.
		 * Using the inverse of the gamma table, because the LED on the 1Bitsy
		 * is on when the PWM signal is low.
		 */
		if ( k ==  0 ) timer_set_oc_value(TIM1, TIM_OC1, 65535 - gamma_table[j0]);
		if ( k ==  1 ) timer_set_oc_value(TIM1, TIM_OC2, 65535 - gamma_table[j0]);
		if ( k ==  2 ) timer_set_oc_value(TIM1, TIM_OC3, 65535 - gamma_table[j0]);
		if ( k ==  3 ) timer_set_oc_value(TIM1, TIM_OC4, 65535 - gamma_table[j0]);
		if ( k ==  4 ) timer_set_oc_value(TIM2, TIM_OC3, 65535 - gamma_table[j0]);
		if ( k ==  5 ) timer_set_oc_value(TIM2, TIM_OC4, 65535 - gamma_table[j0]);
		if ( k ==  6 ) timer_set_oc_value(TIM3, TIM_OC1, 65535 - gamma_table[j0]);
		if ( k ==  7 ) timer_set_oc_value(TIM3, TIM_OC2, 65535 - gamma_table[j0]);
		if ( k ==  8 ) timer_set_oc_value(TIM4, TIM_OC1, 65535 - gamma_table[j0]);
		if ( k ==  9 ) timer_set_oc_value(TIM4, TIM_OC2, 65535 - gamma_table[j0]);
		if ( k == 10 ) timer_set_oc_value(TIM4, TIM_OC3, 65535 - gamma_table[j0]);
		if ( k == 11 ) timer_set_oc_value(TIM4, TIM_OC4, 65535 - gamma_table[j0]);
		if ( k == 12 ) timer_set_oc_value(TIM8, TIM_OC1, 65535 - gamma_table[j0]);
		if ( k == 13 ) timer_set_oc_value(TIM8, TIM_OC2, 65535 - gamma_table[j0]);
		if ( k == 14 ) timer_set_oc_value(TIM8, TIM_OC3, 65535 - gamma_table[j0]);
		if ( k == 15 ) timer_set_oc_value(TIM8, TIM_OC4, 65535 - gamma_table[j0]);

		/* Progress through the gamma table index up and down. */
		j0 += d0;
		if (j0 == 255) {
			d0 = -1;
		}
		if (j0 == 0) {
			d0 = 1;
			k += 1;
			printf("%d\n\r", k);

			t0  = adc_read_single( &temp0  );
			t1  = adc_read_single( &temp1  );
			t2  = adc_read_single( &temp2  );
			t3  = adc_read_single( &temp3  );
			t4  = adc_read_single( &temp4  );
			t5  = adc_read_single( &temp5  );
			t6  = adc_read_single( &temp6  );
			t7  = adc_read_single( &temp7  );
			t8  = adc_read_single( &temp8  );
			t9  = adc_read_single( &temp9  );
			t10 = adc_read_single( &temp10 );
			t11 = adc_read_single( &temp11 );
			t12 = adc_read_single( &temp12 );
			t13 = adc_read_single( &temp13 );
			t14 = adc_read_single( &temp14 );
			t15 = adc_read_single( &temp15 );
		}

		if ( k == 16) {
			k = 0;
		}

		/* Wait a little bit. */
		for (i = 0; i < 10000; i++) asm("nop");

	}

	return 0;
}

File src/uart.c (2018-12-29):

/*
 * This file is part of the 1bitsy project.
 *
 * Copyright (C) 2017 Piotr Esden-Tempski <piotr@esden.net>
 *
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
 * You should have received a copy of the GNU Lesser General Public License
 * along with this library.  If not, see <http://www.gnu.org/licenses/>.
 */

#include <stdlib.h>

#include <libopencm3/stm32/rcc.h>
#include <libopencm3/stm32/gpio.h>
#include <libopencm3/stm32/usart.h>

#include "uart.h"

void uart_init(void)
{
	/* Enable clock for the GPIO bank and USART peripheral blocks. */
	rcc_periph_clock_enable(RCC_GPIOC);
	rcc_periph_clock_enable(RCC_UART5);

	/* Setup GPIO pins for USART3 transmit. */
	gpio_mode_setup(GPIOC, GPIO_MODE_AF, GPIO_PUPD_NONE, GPIO12);

	/* Setup USART3 TX pin as alternate function. */
	gpio_set_af(GPIOC, GPIO_AF8, GPIO12);

	/* Setup USART2 parameters. */
	usart_set_baudrate(UART5, 38400);
	usart_set_databits(UART5, 8);
	usart_set_stopbits(UART5, USART_STOPBITS_1);
	usart_set_mode(UART5, USART_MODE_TX);
	usart_set_parity(UART5, USART_PARITY_NONE);
	usart_set_flow_control(UART5, USART_FLOWCONTROL_NONE);

	/* Finally enable the USART. */
	usart_enable(UART5);
}

size_t uart_write_blocking(const char *buf, size_t len)
{
	for (size_t i = 0; i < len; i++) {
		usart_send_blocking(UART5, buf[i]);
	}

	return len;
}

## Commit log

2018-12-27 Ready for PWM channel tests
2018-12-29 Added UART and ADC functionality
    C11 ended up not being connected to ADC channel 11
    and had to be moved to C1
2019-03-04 First Board Revision Made
    [poseidon.brd, poseidon.sch]
2019-03-31 Added process to use black magic probe to README.
2019-03-31 Fixed problems with first revision, including barrel jack polarity
    Also tidied up labels, connected extra vias to ground, created
    test points for power rails. Still need to fix water level sensor
    connector, which is currently too small.
    [poseidon.brd, poseidon.sch]

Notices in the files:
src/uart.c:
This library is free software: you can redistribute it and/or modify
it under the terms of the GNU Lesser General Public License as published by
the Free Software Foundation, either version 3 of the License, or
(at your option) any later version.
